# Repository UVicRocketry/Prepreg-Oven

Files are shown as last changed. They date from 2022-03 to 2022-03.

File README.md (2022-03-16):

# ThePrepregOvenProject
Circuit diagram, Arduino code, etc. related to the Prepreg Oven Project: Uvic Rocketry's custom composite curing oven! 

The PPO is capable of reading custom temperature profiles from an SD card. Users can load up to 999 profiles with up to 20 target tempertures. Temperature values are linearly interpolated automatically.

## Interface
The oven has 2 buttons for controlling various functions:

**SELECT** Used for scrolling through temperature profiles.

**START/STOP** Confirms temperature profile and starts the oven. Long press to force shut down oven mid cycle. Long press again to reboot the oven.

## Starting the Oven
Upon first power, or after rebooting, the oven displays the profile selection screen. 

Pressing the SELECT button scrolls through the temperature profiles stored on the SD card. The numerical name of the file is displayed, and a short description of the profile appears below.

Once the desired profile is displayed, press START to begin the profile.

## Creating Temperature Profiles
Temperature profiles can be loaded on the SD card for custom cycles.

The format for a profile is a single line in the file as follows:
- Numerical filenames starting at 0. No file extension.
- Exactly 14 alphnumeric characters describing the profile. Pad with spaces if needed. Terminate with a `,`.
- Up to 40 `,` seperated non negative integer values alternating between temperature in C and time between temperatures in seconds. The maximum value of a time number is `65535` (~18h in seconds), and maximum temperature value is `200`.

For example, a profile called `0` containing the single line of text: `Sample        ,20,1800,50,5400,50,1800,80,7200,80,1800,120,1800,120,3600,20` produces the cycle in the image below.

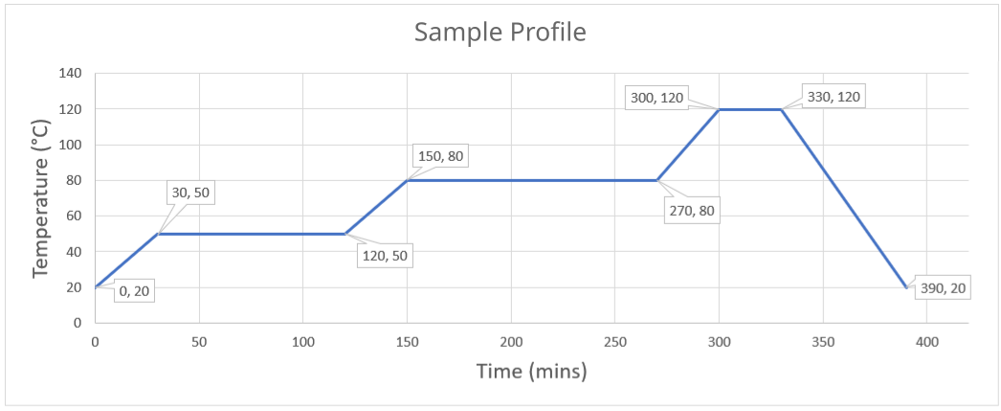
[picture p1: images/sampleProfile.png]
Sample Profile


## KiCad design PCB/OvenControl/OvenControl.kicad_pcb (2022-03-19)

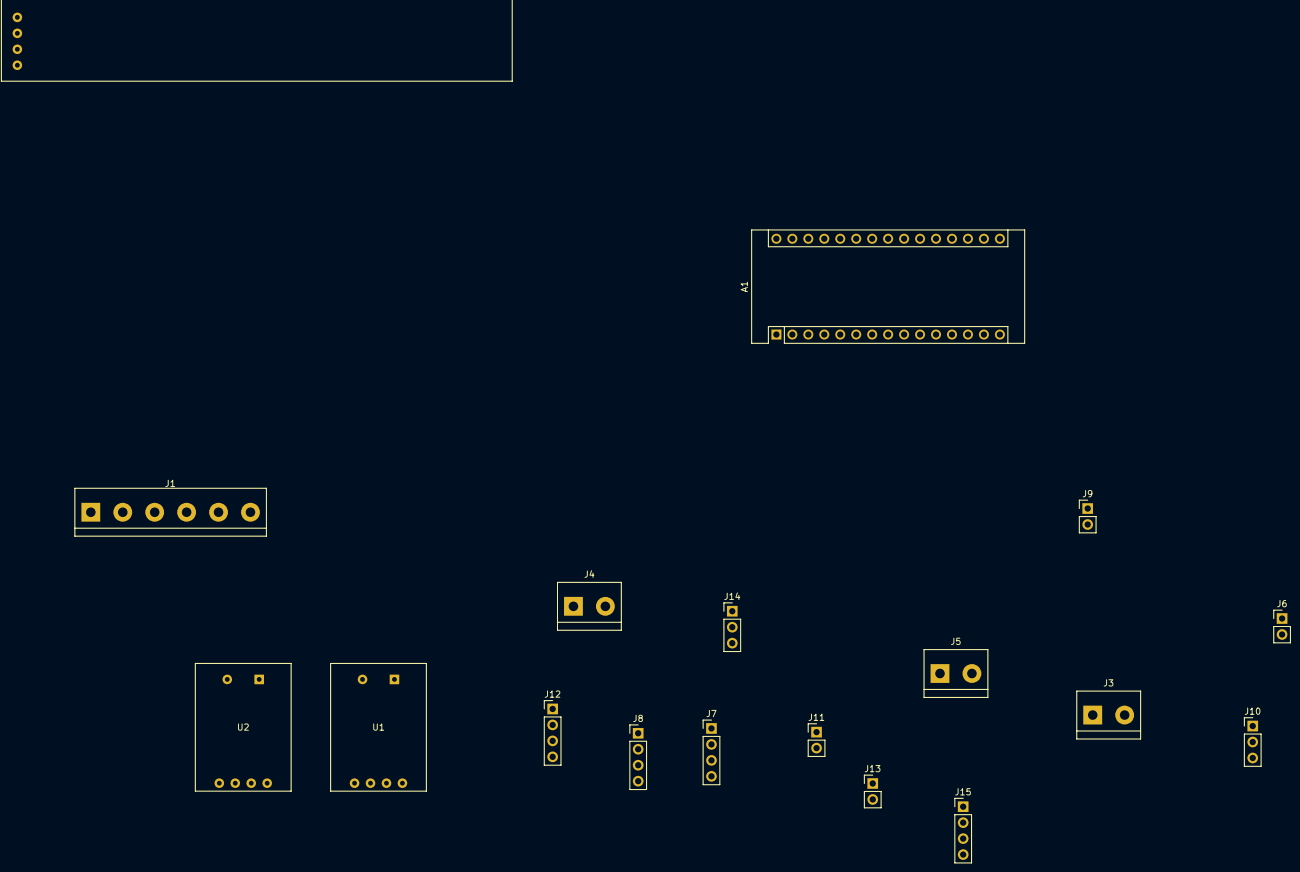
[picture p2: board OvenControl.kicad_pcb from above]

Board: 2 copper layers, 18 parts (0 on the bottom side), 19 nets, no tracks yet.

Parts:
A1: Arduino_Nano_v3.x; Arduino_Nano
J1: Screw_Terminal_01x06; TerminalBlock_bornier-6_P5.08mm
J3, J4, J5: Screw_Terminal_01x02; TerminalBlock_bornier-2_P5.08mm
J6, J9: Conn_01x02_Female; PinHeader_1x02_P2.54mm_Vertical
J7, J8: Conn_01x04_Female; PinHeader_1x04_P2.54mm_Vertical
J10: Conn_01x03_Female; PinHeader_1x03_P2.54mm_Vertical
J11, J13: Conn_01x02_Male; PinHeader_1x02_P2.54mm_Vertical
J12, J15: Conn_01x04_Male; PinHeader_1x04_P2.54mm_Vertical
J14: Conn_01x03_Male; PinHeader_1x03_P2.54mm_Vertical
U1, U2: ADAFRUIT_AD8495; thermoucouple_AD8495
U3: LCD_SCREEN

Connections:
/+5V: A1.27, J8.3, U1.4, U2.4
/+12V: A1.30, J6.1
/AC_Dimmer_PWM: A1.5, J7.2
/AC_Dimmer_Z-C: A1.10, J7.1
/LCD_SDA: A1.23, J8.1
/LCD_SDL: A1.24, J8.2
/Rotary_Encoder1_Input: A1.7, J10.1
/Rotary_Encoder1_PWM: A1.6, J10.2
/Thermocouple1: A1.22, U1.2
/Thermocouple1+: J3.1, U1.5
/Thermocouple1-: J3.2, U1.6
/Thermocouple2: A1.21, U2.2
/Thermocouple2+: J4.1, U2.5
/Thermocouple2-: J4.2, U2.6
GND: A1.4, J5.1, J5.2, J6.2, J7.3, J8.4, J9.2, J10.3, J13.2, J14.3, U1.1, U1.3, U2.1, U2.3
unnamed: J15.1, U3.4
unnamed: J15.2, U3.3
unnamed: J15.3, U3.2
unnamed: J15.4, U3.1

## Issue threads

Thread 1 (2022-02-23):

POAR-1 Simplify existing code

jjderooy, 2022-02-23:
**Description**
The old code was too big to fit on a Nano, and way overly complex.

**Acceptance Criteria**
- Fit on a Nano
- Be simple enough to maintain (no spooky libraries)
- Have simple temperature profiles that can load on SD card
- Follow style guide

**Dev Notes**
[for assignee]<write down your thought process when developing this issue>

Closed 2022-03-18.

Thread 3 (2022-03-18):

Tune PID Loop

klemie, 2022-03-18:
**Description**
Oven uses a PID loop to control temperature. The values of the PID algorithm need to be tuned once the oven is assembled since the values depend on the exact heating characteristics of the physical oven.

**Acceptance Criteria**
Minimal over and undershoot of set temps. Reasonably low settling time (this will depend on Aero lead's discretion).

**Dev Notes**
[for assignee]<write down your thought process when developing this issue>

**Linked issues**
 <If there are any related issues>

<Add to milestone>

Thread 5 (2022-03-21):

Display SD Card CSV

jjderooy, 2022-03-21:
**Description**
The CSV temperature profile needs to be displayed on the screen after selection so the user knows that it was read from the SD card properly.

**Acceptance Criteria**
Display temp and time values from sdTempProfile.temps and sdTempProfile.times on the display.

**Dev Notes**
[for assignee]<write down your thought process when developing this issue>

**Linked issues**
 <If there are any related issues>

<Add to milestone>

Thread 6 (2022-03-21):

Add Check for 200C< Temperatures in Profile

jjderooy, 2022-03-21:
**Description**
Add a check for any temperature values greater than 200C in the SD card profile as the oven is only rated to 200C.

**Acceptance Criteria**
Check profile for >200C temps. Then call ovenDone() with status "Profile too hot (>200C).

**Dev Notes**
[for assignee]<write down your thought process when developing this issue>

**Linked issues**
 <If there are any related issues>

<Add to milestone>

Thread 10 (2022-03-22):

Log True Temperature to SD Card

jjderooy, 2022-03-22:
**Description**
It would be helpful to log the measured temperature during the profile to the SD card so the user can download the data later for analysis.

**Acceptance Criteria**
Log temperature to a file on the SD card throughout the cycle.

**Dev Notes**
[for assignee]<write down your thought process when developing this issue>

**Linked issues**
 <If there are any related issues>

<Add to milestone>

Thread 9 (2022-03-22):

Linear Interpolation Bug

jjderooy, 2022-03-22:
**Description**
When interpolateTemp calculates the target temp, it calculates a decreasing value that eventually drops below the final stage temp even if the stage temp is higher than the current temp.

**Acceptance Criteria**
interpolateTemp should do a proper interpolation.

**Dev Notes**
[for assignee]<write down your thought process when developing this issue>

**Linked issues**
 <If there are any related issues>

<Add to milestone>

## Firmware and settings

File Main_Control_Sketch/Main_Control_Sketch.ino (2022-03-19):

/*
    Prepreg Oven Main Control Sketch

    This sketch controls the oven using a PID loop with the output connected to
    an AC heater circuit. 
    
    Buttons are used to control the settings on an LCD and 2 thermocouples are
    used for feedback. A microSD card provides a convenient way to load
    temperature profiles with linearly interpolated values.

    See README for temperature profile structure.

    Author: JJ D

    UVic Rocketry
    October 2022
*/

#include <Wire.h>
#include <LiquidCrystal_I2C.h>

// https://github.com/fabianoriccardi/dimmable-light
#include <dimmable_light.h>

/* 
    SD Card library that is extra small to save ram.
    Note that the library's chip select pin by default is 10.
*/
#include <PetitFS.h>
#include <PetitSerial.h>

// ***** PINS ***** //

// Dimmer breakout board
#define HEATER_INT  2 // Interrupt capable
#define HEATER_CTRL 3

// Thermocouple breakout boards
#define THERMOCOUPLE_1 A0
#define THERMOCOUPLE_2 A1

#define START_STOP_BTN 4
#define SELECT_BTN 5


// ***** OBJECTS ***** //

// Heater dimmer object
DimmableLight heater(HEATER_CTRL);

// Instantiate our LCD
LiquidCrystal_I2C lcd(0x3F, 20, 4);

// MicroSD card
PetitSerial PS;
#define Serial PS
FATFS fs;

// Temperature profile read from SD card.
struct tempProfile
{
    // Name of the file on the SD card
    byte fileNumber = 0;

    // 14 char description of profile. First chars in file.
    char description[15];

    // Location in temps and times array
    byte index = 0;

    // Set by profile on SD card
    byte temps[20] = {0};
    unsigned int times[20] = {0};
};

// ***** GLOBALS ***** //

// Set by START_STOP_BTN
bool ovenStarted = false;
bool ovenFinished = false;

// PID loop
// TODO tune these PID values. 
#define kP 1.0
#define kI 1.0
#define kD 1.0
#define intThresh 10   // Prevents "integral windup". See set_PID_heater()
#define PIDScale 0.1   // Scales PID value to roughly 0-100
float prevError = 0;   // Error of the previous PID calculation
float integral  = 0;   // Accumulation of integral values in PID
long  timerDt   = 0;   // Tracks millis() for PID dt value

// Value of millis() when the next temp in the profile was set
unsigned long millisStageStarted = 0;

unsigned long lastMillis = millis();

tempProfile sdTempProfile;

// Allows reset of Arduino through software
void(* resetFunc) (void) = 0;

void setup()
{
    Serial.begin(9600);

    pinMode(START_STOP_BTN, INPUT_PULLUP);
    pinMode(SELECT_BTN, INPUT_PULLUP);

	// Initialize the display
    lcd.init();
    lcd.backlight();
    lcd.clear();

    // Set up the heater dimmer object
    DimmableLight::setSyncPin(HEATER_INT);
    DimmableLight::begin();

    // Init the SD card
    if(pf_mount(&fs))
    {
        lcd.setCursor(1,1);
        ovenDone(F("SD Mount Failed"));
    }

    
    // Read first profile to show its description w/o a button press
    readSDProfile();

    // Temperature profile selection
    configureOven();
}

void loop()
{
    // Check for force shutdown/restart
    checkButtons();

    // Update display at 1Hz
    if(millis() - lastMillis > 1000)
    {
        updateDisplay(
            30,
            interpolateTemp(),
            sdTempProfile.temps[sdTempProfile.index],
            sdTempProfile.times[sdTempProfile.index] - (millis() - millisStageStarted)/1000,
            getTotalTimeRemaining()
            );

        lastMillis = millis();
    }

    // profile array contains 20 values max. Finished if end is reached
    if(sdTempProfile.index >= 20)
        ovenDone("Cycle Complete!");

    // Move to next stage in profile if needed
    if((millis() - millisStageStarted)/1000 > sdTempProfile.times[sdTempProfile.index])
    {
        sdTempProfile.index++;
        millisStageStarted = millis();
    }

    setHeaterPowerPID(measureTemp(), interpolateTemp(), millis() - timerDt);
    timerDt = millis();
}

void configureOven()
{
    lcd.clear();

    while(!ovenStarted)
    {
        checkButtons();

        lcd.setCursor(0,0);
        lcd.print(F("Selected cycle: "));
        lcd.print(sdTempProfile.fileNumber);

        lcd.setCursor(0,1);
        lcd.print(F("Desc: "));
        lcd.print(sdTempProfile.description);

        lcd.setCursor(0,3);
        lcd.print("   Press Start...");
    }

    lcd.clear();
    lcd.setCursor(0,1);

    // Memesssss
    switch (millis() % 24)
    {
    case 0:
        lcd.print(F("Hydrate or Die-drate"));
        break;

    case 1:
        lcd.print(F("     Mech Monkee"));
        lcd.setCursor(0,2);
        lcd.print(F("      Certified"));
        break;
        
    case 2:
        lcd.print(F("   Solidworks has"));
        lcd.setCursor(0,2);
        lcd.print(F("encountered an error"));
        break;

    case 3:
        lcd.print(F("  Has MULE-1 been"));
        lcd.setCursor(0,2);
        lcd.print(F("   hotfired yet??"));
        break;

    case 4:
        lcd.print(F("   Gucci to Gochi"));
        break;

    case 5:
        lcd.print(F("To the Katz-Mobile!"));
        break;

    case 6:
        lcd.print(F("Wrangling Pixies..."));
        break;

    case 7:
        lcd.print(F("   I hope Xenia-1"));
        lcd.setCursor(0,2);
        lcd.print(F("   didn't crash"));
        break;

    case 8:
        lcd.print(F("  Hello it's your"));
        lcd.setCursor(0,2);
        lcd.print(F("   overlord Kris"));
        break;

    case 9:
        lcd.print(F("   This oven fits"));
        lcd.setCursor(0,2);
        lcd.print(F("  one Devon inside"));
        break;

    case 10:
        lcd.print(F("   I use VIM btw"));
        break;

    case 11:
        lcd.print(F("   Also great for"));
        lcd.setCursor(0,2);
        lcd.print(F("   baking bread!"));
        break;

    case 12:
        lcd.setCursor(0,0);
        lcd.print(F("  3 C White Flour"));
        lcd.setCursor(0,1);
        lcd.print(F("   3/4 C Starter"));
        lcd.setCursor(0,2);
        lcd.print(F("   1 1/4 C Water"));
        lcd.setCursor(0,3);
        lcd.print(F("   1/2 TBSP Salt"));
        break;

    case 13:
        lcd.print(F(" Liberate the HAAS!"));
        break;

    case 14:
        lcd.print(F("   Post and plate"));
        lcd.setCursor(0,2);
        lcd.print(F("      babyyyyy"));
        break;

    case 15:
        lcd.print(F("    Snitches get"));
        lcd.setCursor(0,2);
        lcd.print(F("      Stitches"));
        break;

    case 16:
        lcd.print(F("  Migrating to the"));
        lcd.setCursor(0,2);
        lcd.print(F("   new server..."));
        break;

    case 17:
        lcd.print(F(" Migrating from the"));
        lcd.setCursor(0,2);
        lcd.print(F("   new server..."));
        break;

    case 18:
        lcd.print(F("Invest in UVR Coin!"));
        break;

    case 19:
        lcd.setCursor(0,3);
        lcd.print(F("    Bottom Text"));
        break;

    case 20:
        lcd.setCursor(0,0);
        lcd.print(F("   o   Ideal"));
        lcd.setCursor(0,1);
        lcd.print(F("   |   Electrical"));
        lcd.setCursor(0,2);
        lcd.print(F("  _|_  Engineer"));
        lcd.setCursor(0,3);
        lcd.print(F("   ^"));
        break;

    case 21:
        lcd.print(F("   Sponsored by"));
        lcd.setCursor(0,2);
        lcd.print(F("    Aliexpress"));
        break;

    case 22:
        lcd.print(F("JunCAD is Converging"));
        break;

    case 23:
        lcd.print(F("  Same hairea tho"));
        break;

    case 24:
        lcd.print(F(" In thrust we trust"));
        break;

    default:
        break;
    }

    delay(2000);
    lcd.clear();
    delay(1000);

    // Set start of first stage
    millisStageStarted = millis();

    // This jumps to void loop()
}

void updateDisplay(byte realTemp, byte setTemp, byte finalStageTemp,
                    unsigned int secondsToNextTemp,
                    unsigned long totalSecondsRemaining)
{
    /*
        Display is 4 lines, 20 char each

        // All in degrees science (C)
        realTemp = 118
        setTemp = 120
        finalStageTemp = 150

        secondsToNextTemp = 1620 (27 minutes)
        totalSecondsRemaining = 13320 (3.7 hours)
        _____________________
        |Real 118  Target 120|
        |Final stage temp 150|
        |27m left in stage   |
        |3.7h remaining      |

    */

    lcd.clear();

    // Format seconds to hours or minutes

    // totalSecondsRemaining
    String totalRemainingStr = "";

    if(totalSecondsRemaining > 3600)
        totalRemainingStr = String(float(totalSecondsRemaining)/3600.0, 1) + "h";
    else if(totalSecondsRemaining > 60)
        totalRemainingStr = String(totalSecondsRemaining / 60) + "m";
    else
        totalRemainingStr = "<1m";

    // secondsToNextTemp
    String nextTempStr = "";

    if(secondsToNextTemp > 3600)
        nextTempStr = String(float(secondsToNextTemp)/3600.0, 1) + "h";
    else if(totalSecondsRemaining > 60)
        nextTempStr = String(secondsToNextTemp / 60) + "m";
    else
        nextTempStr = "<1m";

    // Printing to the lcd line by line
    lcd.setCursor(0,0);
    lcd.print(F("Real "));
    lcd.print(realTemp);
    lcd.setCursor(10,0);
    lcd.print(F("Target "));
    lcd.print(setTemp);

    lcd.setCursor(0,1);
    lcd.print(F("Final stage temp "));
    lcd.print(finalStageTemp);

    lcd.setCursor(0,2);
    lcd.print(nextTempStr);
    lcd.print(F(" left in stage"));
    
    lcd.setCursor(0,3);
    lcd.print(totalRemainingStr);
    lcd.print(F(" remaining"));
}

void checkButtons()
{
    // Select button scrolls through temperature profiles on SD card
    if(digitalRead(SELECT_BTN) == LOW && !ovenStarted)
    {
        sdTempProfile.fileNumber++;
        readSDProfile();
    }

    // Start button
    if(digitalRead(START_STOP_BTN) == LOW)
        ovenStarted = true;

    // 3s long press to shut down or reset oven
    int timePressed = 0;
    while (digitalRead(START_STOP_BTN) == LOW && timePressed <= 3000)
    {
        delay(100);
        timePressed += 100;
    }

    if(timePressed >= 3000 && ovenFinished)
        resetFunc();
    if(timePressed >= 3000 && ovenStarted)
        ovenDone(F("Force Shutdown"));
}

void readSDProfile()
{
    // IF THERE ARE ANY BUGS IN THE CODE THEY ARE PROBABLY HERE

    // Clear the profile arrays
    for(int i = 0; i < 20; i++)
    {
        sdTempProfile.temps[i] = 0;
        sdTempProfile.times[i] = 0;
    }

    // Convert fileNumber to char array
    char fileName[4] = "   ";
    itoa(sdTempProfile.fileNumber, fileName, 10);

    // Loop back and open 0 if no higher file exists
    if(pf_open(fileName))
    {
        sdTempProfile.fileNumber = 0;
        pf_open("0");
    }

    // Update sdTempProfile with the contents of the file

    // Read the description (first 14 chars)
    UINT bytesRead;
    pf_read(sdTempProfile.description, 14, &bytesRead);

    // Move past the comma after description
    pf_lseek(fs.fptr + 1);


    // Next read csv into sdTempProfile.

    // 5 char is enough to store max value of unsigned int
    char charsNum[6];
    
    // Index in charsNum 
    byte charIndex = 0;

    // Index in temps/times array in sdTempProfile
    byte profileIndex = 0;

    // true means temp, false means time
    bool isTemp = true;     

    // bytesRead = 0 when EOF is reached
    while(bytesRead > 0) 
    {
        pf_read(&charsNum[charIndex], 1, &bytesRead);

        // Comma or EOF reached
        if(bytesRead < 1 || !isDigit(charsNum[charIndex]))
        {
            charsNum[charIndex] = '\0';
            String strNum = String(charsNum);

            // Convert and store value in profile
            // This breaks if profile contains too large of numbers
            if(isTemp){
                sdTempProfile.temps[profileIndex] = strNum.toInt();
                isTemp = false;
            }
            else
            {
                sdTempProfile.times[profileIndex] = strNum.toInt();
                profileIndex++;
                isTemp = true;
            }

            // Prepare to get next number string
            charIndex = 0;
        }
        else
            charIndex++;
    }

    // Debounce
    delay(250);
}

byte interpolateTemp()
{
    // Linearly interpolates values when temperature profile ramps
    // (y) = y1 + [(x-x1) × (dy)]/ (dx) where y is interpolated temp

    byte i = sdTempProfile.index;

    float dx = sdTempProfile.times[i+1] - sdTempProfile.times[i];
    float dy = sdTempProfile.temps[i+1] - sdTempProfile.temps[i];

    return sdTempProfile.temps[i] + ( (float((millisStageStarted - millis()))*dy) / dx );
}

unsigned long getTotalTimeRemaining()
{
    unsigned long sum = 0;

    // This is guaranteed to add at least the last value in times to sum
    for(byte i = sdTempProfile.index; i < 20; i++)
        sum += sdTempProfile.times[i];

    // Subtract mid-stage time elapsed.
    sum -= (millis() - millisStageStarted)/1000;
    Serial.println(sum);
    return sum;
}

int measureTemp()
{
	// This is based on: adafruits ad8495 article
    
    #define AREF 4.5 // Nano is 4.5V 
    #define ADC_RESOLUTION 10 // Nano is 10 bit

	// Get the raw voltage pin on the thermocouple pin
	float voltage = 0.5*(analogRead(THERMOCOUPLE_2) + analogRead(THERMOCOUPLE_1))
                    * (AREF / (pow(2, ADC_RESOLUTION) - 1));

    // Convert the voltage to a value in C 
    // Adjust the x in (voltage-x) to tune the temperature.
    return (voltage - 1.59) / 0.005;
}

void setHeaterPowerPID(byte realTemp, byte targetTemp, float dt)
{

    float error = targetTemp - realTemp;

    // We only include integral when the oven is already
    // within intThresh degrees of the tempSet to prevent it from dominating
    // This behaviour is called "integral windup"
    if(abs(error) < intThresh)
        integral += error*dt / 1000; // ms->s
    else
        integral = 0;

    float derivative = (error - prevError) / dt;
    float pwr = (error*kP) + (integral*kI) + (derivative*kD);

    pwr *= PIDScale;

    // The circuit is not rated for the full power of the heater
    // so we limit the values to 0-100 rather than 0-255
    if(pwr > 100)
        pwr = 100;
    else if(pwr < 0)
        pwr = 0;

    heater.setBrightness(pwr);

    prevError = error;
}

// Status 20 chars max
void ovenDone(String status)
{
    heater.setBrightness(0);
    ovenFinished = true;
    lcd.clear();

    while(true)
    {
        // Update display 1Hz
        if(millis() - lastMillis > 1000)
        {
            // Status message explaining shutdown reason
            lcd.setCursor(0,0);
            lcd.print(status);

            // Let user know if oven is cooled off yet
            lcd.setCursor(0,1);
            lcd.print(F("Temperature:       "));
            lcd.setCursor(14, 1);
            lcd.print(String(measureTemp()));

            lcd.setCursor(0,3);
            lcd.print(F("Hold Start to reset"));
            lastMillis = millis();
        }

        // Check for reset signal
        checkButtons();
    }
}

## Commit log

2022-03-13 Add full SD support. Remove some bugs
    [Main_Control_Sketch.ino]
2022-03-13 Fix profile array overwriting bug
    [Main_Control_Sketch.ino]
2022-03-16 Add PID loop
2022-03-19 Add GrabCAD PCB files
    [OvenControl.kicad_pcb, OvenControl.kicad_sch, OvenControl.sch]
2022-04-14 Add wiring diagram
    [Oven_Wiring_Layout_v.2.kicad_sch]
